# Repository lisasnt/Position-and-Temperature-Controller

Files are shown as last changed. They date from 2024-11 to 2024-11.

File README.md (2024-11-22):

# Position-and-Temperature-Controller

## About the project 
Nowadays, more and more biomedical applications require the implementation of embedded systems, to ensure performance and reliability while keeping costs down. Currently, at the laboratories of Pro-M Facility it's developed a calibration plant for a machine used in proton therapy. 

The goal of this application is to reduce the time taken for the calibration procedure of the machinery, making the process completely autonomous and without revision, thus reducing the duration of the operation from a couple of hours to a few tens of minutes.

The project consists in the development of the measurement and control part, in support of the innovative design proposed by the company, made using: an STM32H7 microcontroller, an absolute magnetic encoder and temperature sensors.

During the entire process a bottom-up approach was used, starting from the firmware and hardware development of the individual components, and then creating interconnections between them. 

The project has been successfully completed and, at the present time, is fully integrated within the macro project of Pro-M Facility.

## Components used

Main components used for the project:
- Nucleo STM32H723ZG
- Magnetic encoder WDGA 36A
- PTC thermistor
- NTC thermistor
- Custom PCB shield
- IHM03A1 step motor driver

# The main project

The entire system is called _Matrixx_ and consists of a mechanical structure needed to support the motor and a sensors control part (this one made by us). The Python GUI and the low level drivers to drive the motor are not shown in this repo because of a nondisclosure agreement with the company. 

[Matrixx project demo video](media/Embedded%20System%20Video%20-%20Proton.mp4)

## Custom PCB shield
This PCB allows the microcontroller to handle different voltages to supply all the internal and external components (involved voltages: 3.3, 5, 24 V)<br><br>
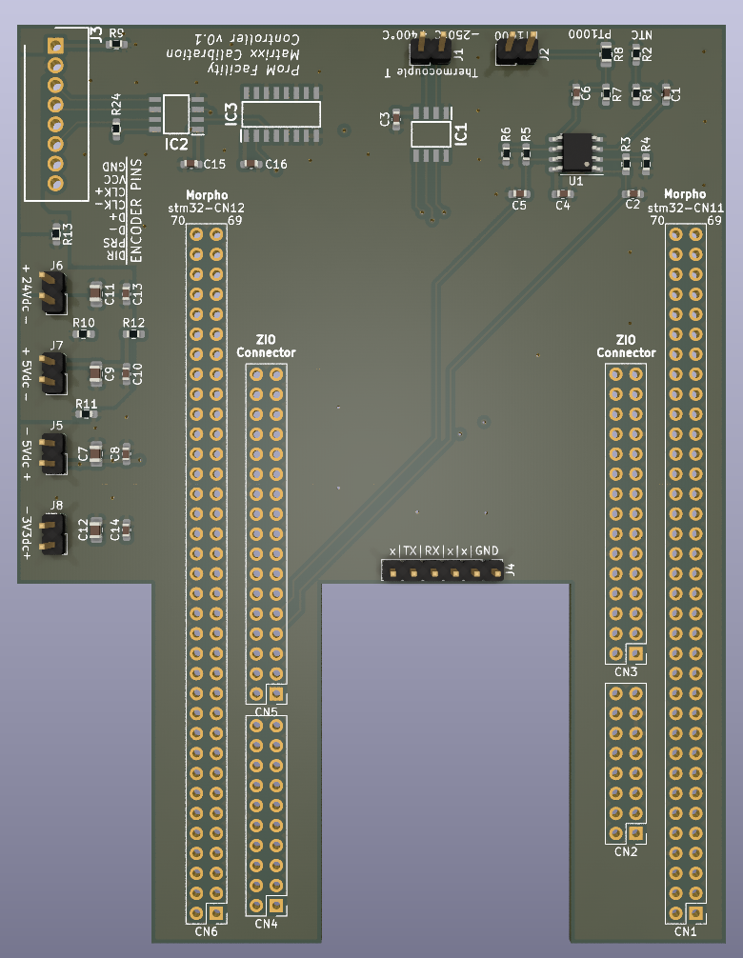
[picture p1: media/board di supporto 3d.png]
custom shield pcb

<br>_The custom PCB used as shield_<br><br>
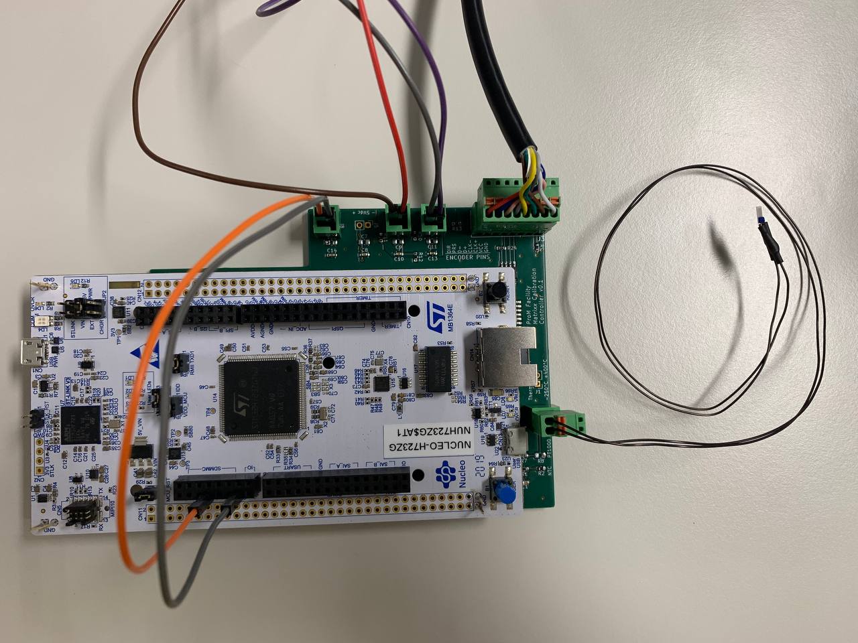
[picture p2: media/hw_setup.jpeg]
mounted board

<br>_The control subsystem made by us_

# Build and Run
## Repo structure
    📂 Firmware
    ┣ 📂 STM F4 <- it's not the version considered in the project
    ┣ 📂 STM H7 
    📂 Hardware
    ┣ 📂 HW_Encoder_Driver_Board <- just a prototype
    ┣ 📂 HW_Temperature_Sensors_Board <- Kicad project of the PCB shield

## Build the code and run
- Open STM32 Cube IDE
- `File` > `Import` > `Existing projects into Workspace`
- Select the root directory where the project is located
- Press `Finish`

Then you can build and run using the IDE

# Report
[Full report](/Academic_Project_Report.pdf)

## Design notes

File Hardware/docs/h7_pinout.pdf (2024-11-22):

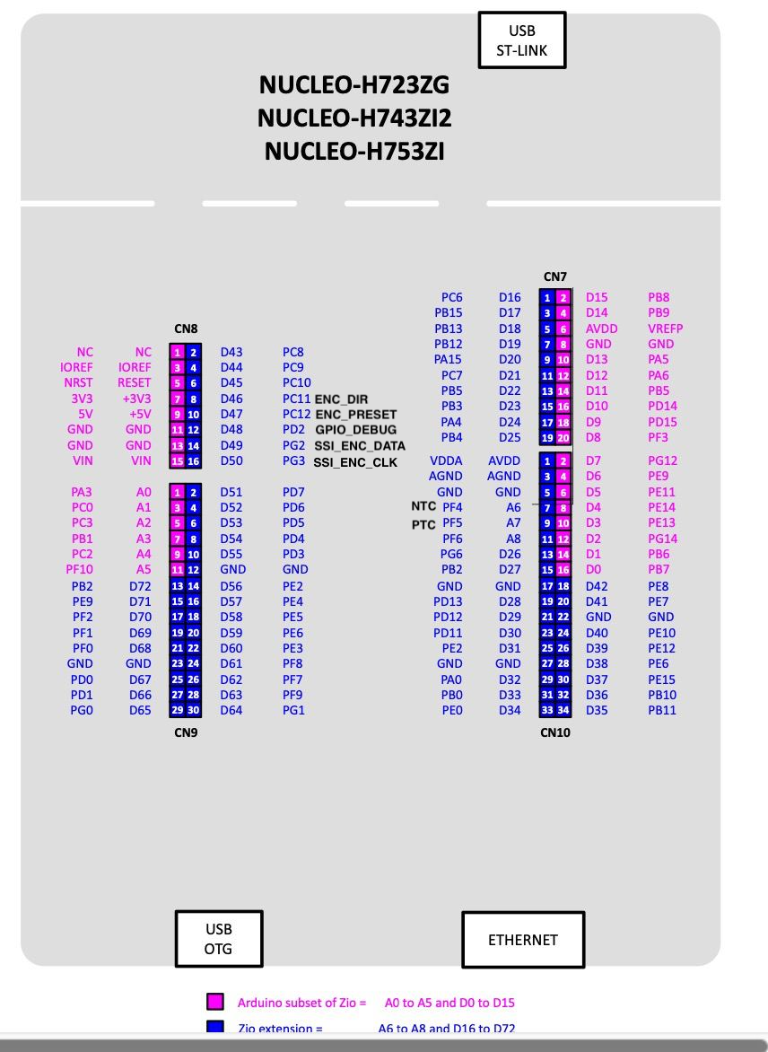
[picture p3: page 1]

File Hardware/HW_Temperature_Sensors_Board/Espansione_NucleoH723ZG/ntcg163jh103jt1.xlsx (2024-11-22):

P/N | NTCG163JH103JT1
R25 | 10 | kƒ¶ +/- | 5 | % |  |  |  |  |  |  |  |  |  | 2718334.pdf (farnell.com) (https://www.farnell.com/datasheets/2718334.pdf)
B25/85 | 3435 | K +/- | 3 | % |  |  | R kOhm | 10 |  |  | Ra | 10 |  | How to Use Temperature Protection Devices : Chip NTC Thermistors | Application Note | Tech Library | TDK Product Center (https://product.tdk.com/en/techlibrary/applicationnote/howto_chip-ntc-thermistor.html)
 |  |  |  |  |  |  | Vdd | 3.3 |  |  | Rb | 2.2
Temp | Min | Nom | Max | B25/T | -dT | dT
(degC) | (k ohm) | (k ohm) | (k ohm) | (K) | (degC) | (degC) | Vout-div (B) | Vout-div (T) | Ivdiv | V*I | Vout-ampli (T) |  | Vout-ampli (B)
-40 | 164 | 188.5 | 216.2 | 3140 | -2.4 | 2.4 | 3.133753149 | 0.1662468514 | 1.662468514e-05 | 2.76380156e-06 | 0.2028211587 |  | 3.823178841
-39 | 155.6 | 178.6 | 204.4 | 3144 | -2.4 | 2.4 | 3.125026511 | 0.1749734889 | 1.749734889e-05 | 3.061572181e-06 | 0.2134676564 |  | 3.812532344
-38 | 147.7 | 169.2 | 193.4 | 3148 | -2.4 | 2.4 | 3.115848214 | 0.1841517857 | 1.841517857e-05 | 3.391188018e-06 | 0.2246651786 |  | 3.801334821
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

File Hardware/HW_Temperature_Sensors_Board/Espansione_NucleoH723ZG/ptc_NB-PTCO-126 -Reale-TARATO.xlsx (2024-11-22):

P/N | NB-PTCO-126 |  | a | 0.0039083
TCR | 3850 | ppm/°C | b | -5.775e-07 |  |  |  |  |  |  |  | 2305684.pdf (farnell.com) (https://www.farnell.com/datasheets/2305684.pdf)
R 0°C | 1000 | ohm | c | -4.183e-12 | R kOhm | 6.8 |  |  | Ra | 2.28
 |  |  |  |  | Vdd | 3.3 |  |  | Rb | 10 |  | dr 0-100 | 0.7289419342 | Gain | 5.385964912
Temp |  | Nom
(degC) |  | (k ohm) |  |  | Vout-div (B) | Vout-div (T) | Ivdiv | V*I | Vout-ampli (T) |  | Vout-ampli (B)
-40 |  | 0.84 |  |  | 0.3638673695 | 2.936132631 | 0.0004317842104 | 0.001267775709 | 15.81390733 |  | 1.959776885
-39 |  | 0.85 |  |  | 0.3653867273 | 2.934613273 | 0.0004315607754 | 0.001266463979 | 15.80572412 |  | 1.967960093
-38 |  | 0.85 |  |  | 0.3669040039 | 2.933095996 | 0.0004313376465 | 0.001265154724 | 15.79755212 |  | 1.976132091
-37 |  | 0.85 |  |  | 0.3684192058 | 2.931580794 | 0.0004311148227 | 0.001263847934 | 15.7893913 |  | 1.984292915
-36 |  | 0.86 |  |  | 0.3699323393 | 2.930067661 | 0.000430892303 | 0.001262543602 | 15.78124161 |  | 1.992442599
-35 |  | 0.86 |  |  | 0.3714434107 | 2.928556589 | 0.0004306700867 | 0.00126124172 | 15.77310303 |  | 2.000581177
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

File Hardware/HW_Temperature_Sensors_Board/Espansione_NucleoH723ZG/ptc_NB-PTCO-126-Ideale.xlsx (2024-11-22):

P/N | NB-PTCO-126 |  | a | 0.0039083
TCR | 3850 | ppm/°C | b | -5.775e-07 |  |  |  |  |  |  |  | 2305684.pdf (farnell.com) (https://www.farnell.com/datasheets/2305684.pdf)
R 0°C | 1000 | ohm | c | -4.183e-12 | R kOhm | 6.8 |  |  | Ra | 2.4
 |  |  |  |  | Vdd | 3.3 |  |  | Rb | 10 |  | dr 0-100 | 0.699261888
Temp |  | Nom
(degC) |  | (k ohm) |  |  | Vout-div (B) | Vout-div (T) | Ivdiv | V*I | Vout-ampli (T) |  | Vout-ampli (B)
-40 |  | 0.84 |  |  | 0.3638673695 | 2.936132631 | 0.0004317842104 | 0.001267775709 | 15.17001859 |  | 1.879981409
-39 |  | 0.85 |  |  | 0.3653867273 | 2.934613273 | 0.0004315607754 | 0.001266463979 | 15.16216858 |  | 1.887831424
-38 |  | 0.85 |  |  | 0.3669040039 | 2.933095996 | 0.0004313376465 | 0.001265154724 | 15.15432931 |  | 1.895670687
-37 |  | 0.85 |  |  | 0.3684192058 | 2.931580794 | 0.0004311148227 | 0.001263847934 | 15.14650077 |  | 1.90349923
-36 |  | 0.86 |  |  | 0.3699323393 | 2.930067661 | 0.000430892303 | 0.001262543602 | 15.13868291 |  | 1.911317086
-35 |  | 0.86 |  |  | 0.3714434107 | 2.928556589 | 0.0004306700867 | 0.00126124172 | 15.13087571 |  | 1.919124289
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

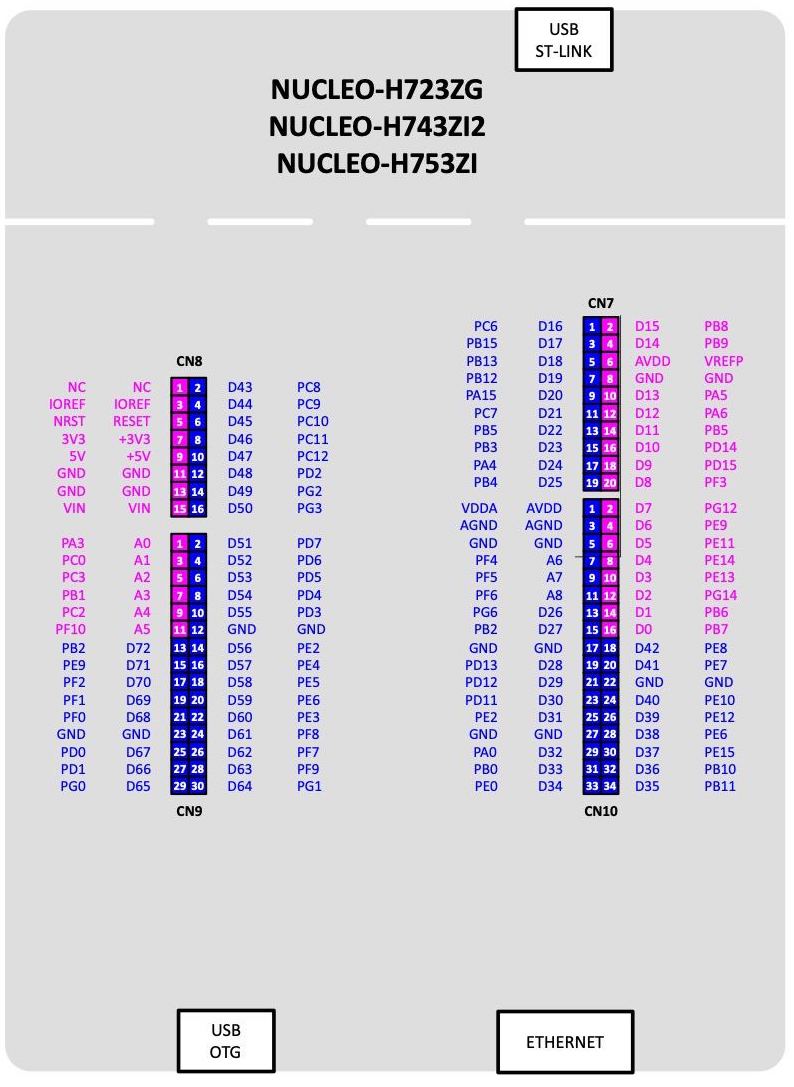
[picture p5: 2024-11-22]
media/pinout_stm.jpg

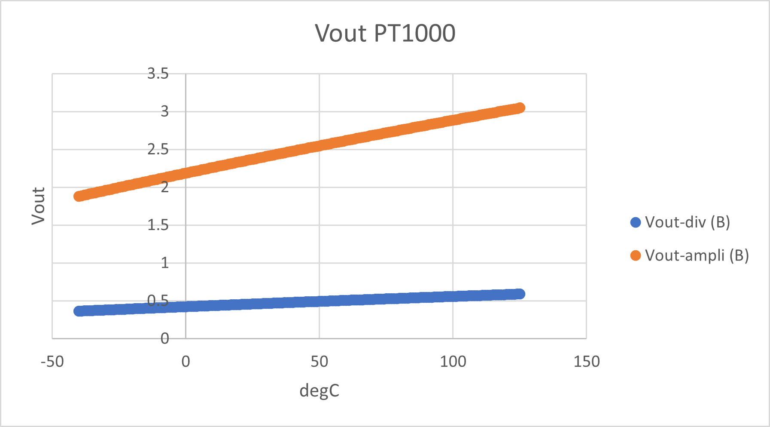
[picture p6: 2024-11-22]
Hardware/HW_Temperature_Sensors_Board/Espansione_NucleoH723ZG/Kicad_pj/pt1000_out.png

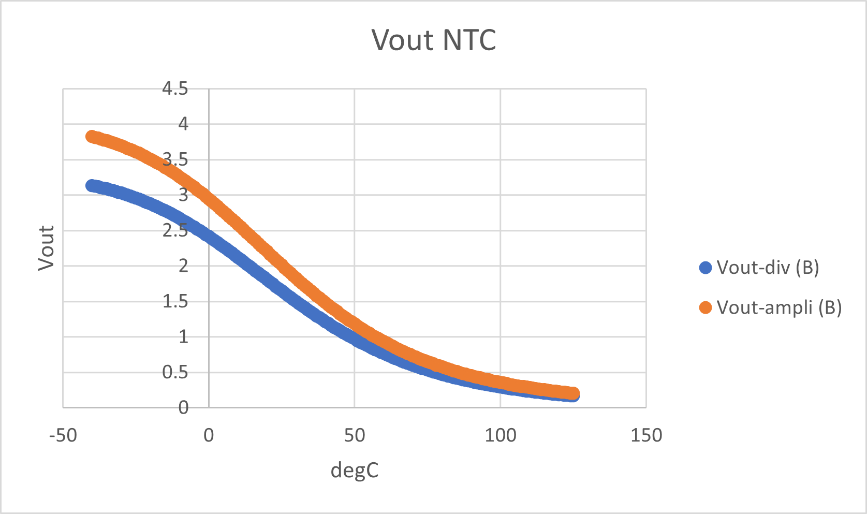
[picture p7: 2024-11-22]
Hardware/HW_Temperature_Sensors_Board/Espansione_NucleoH723ZG/Kicad_pj/ntc_out.png

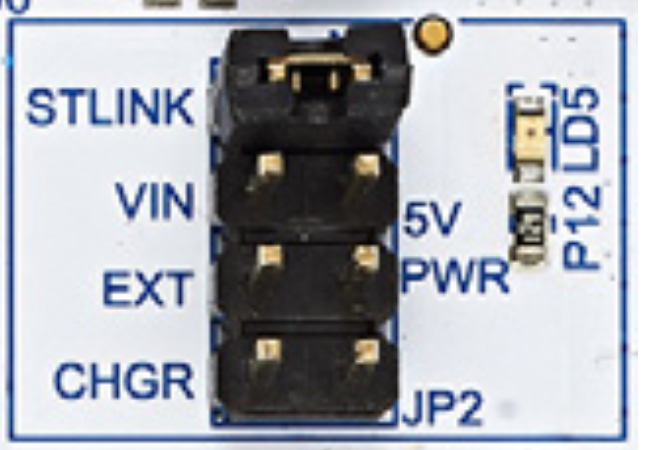
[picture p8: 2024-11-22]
media/jp2.png

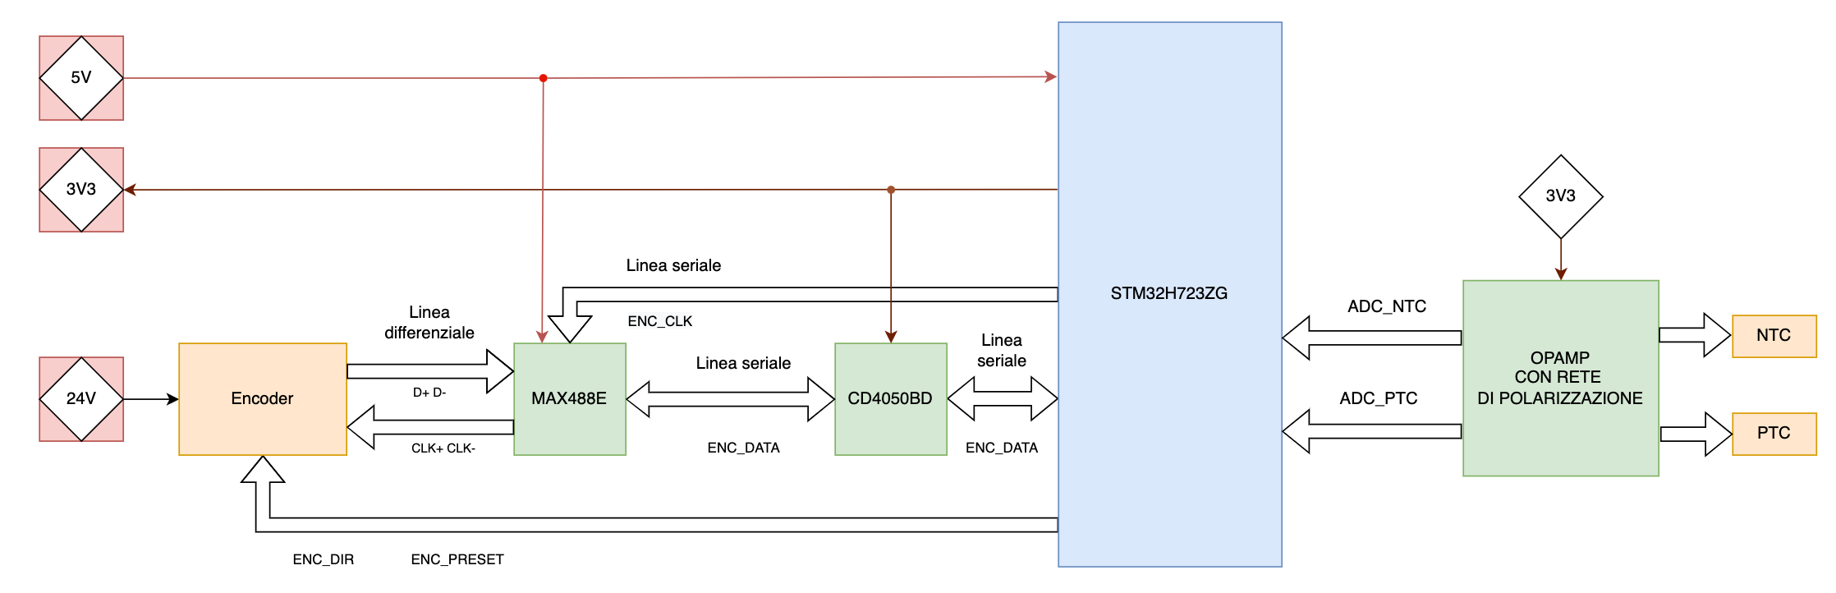
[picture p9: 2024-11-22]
media/Schema a blocchi board.png

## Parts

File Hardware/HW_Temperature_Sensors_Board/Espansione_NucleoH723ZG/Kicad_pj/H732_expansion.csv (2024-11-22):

Source: | C:\Users\maurizio.rossi\Documents\Projects\[2021][11] Proton Gantry\espansione\H732_expansion\H732_expansion.kicad_sch
Date: | 3/7/2022 11:16
Tool: | Eeschema (6.0.1)
Generator: | C:\Program Files\KiCad\bin\scripting\plugins/bom_csv_grouped_by_value_with_fp.py
Component Count: | 60
Ref | Qnty | Value | Cmp name | Footprint | Description | Vendor
C1, C2, C5, C6, | 4 | 10n | C_Small | Capacitor_SMD:C_0603_1608Metric_Pad1.08x0.95mm_HandSolder | Unpolarized capacitor, small symbol
C3, C4, C15, C16, | 4 | 100n | C_Small | Capacitor_SMD:C_0603_1608Metric_Pad1.08x0.95mm_HandSolder | Unpolarized capacitor, small symbol
C7, C9, C12, | 3 | 1u 10V | C_Small | Capacitor_SMD:C_0805_2012Metric_Pad1.18x1.45mm_HandSolder | Unpolarized capacitor, small symbol
C8, C10, C14, | 3 | 100n 10V | C_Small | Capacitor_SMD:C_0603_1608Metric_Pad1.08x0.95mm_HandSolder | Unpolarized capacitor, small symbol
C11, | 1 | 1u 50V | C_Small | Capacitor_SMD:C_0805_2012Metric_Pad1.18x1.45mm_HandSolder | Unpolarized capacitor, small symbol
C13, | 1 | 100n 50V | C_Small | Capacitor_SMD:C_0603_1608Metric_Pad1.08x0.95mm_HandSolder | Unpolarized capacitor, small symbol
CN1, | 1 | CN11 | Conn_02x35_Odd_Even | Connector_PinHeader_2.54mm:PinHeader_2x35_P2.54mm_Vertical | Generic connector, double row, 02x35, odd/even pin numbering scheme (row 1 odd numbers, row 2 even numbers), script generated (kicad-library-utils/schlib/autogen/connector/)
CN2, | 1 | CN8 | Conn_02x08_Odd_Even | Connector_PinHeader_2.54mm:PinHeader_2x08_P2.54mm_Vertical | Generic connector, double row, 02x08, odd/even pin numbering scheme (row 1 odd numbers, row 2 even numbers), script generated (kicad-library-utils/schlib/autogen/connector/)
CN3, | 1 | CN9 | Conn_02x15_Odd_Even | Connector_PinHeader_2.54mm:PinHeader_2x15_P2.54mm_Vertical | Generic connector, double row, 02x15, odd/even pin numbering scheme (row 1 odd numbers, row 2 even numbers), script generated (kicad-library-utils/schlib/autogen/connector/)
CN4, | 1 | CN7 | Conn_02x10_Odd_Even | Connector_PinHeader_2.54mm:PinHeader_2x10_P2.54mm_Vertical | Generic connector, double row, 02x10, odd/even pin numbering scheme (row 1 odd numbers, row 2 even numbers), script generated (kicad-library-utils/schlib/autogen/connector/)
CN5, | 1 | CN10 | Conn_02x17_Odd_Even | Connector_PinHeader_2.54mm:PinHeader_2x17_P2.54mm_Vertical | Generic connector, double row, 02x17, odd/even pin numbering scheme (row 1 odd numbers, row 2 even numbers), script generated (kicad-library-utils/schlib/autogen/connector/)
CN6, | 1 | C12 | Conn_02x35_Odd_Even | Connector_PinHeader_2.54mm:PinHeader_2x35_P2.54mm_Vertical | Generic connector, double row, 02x35, odd/even pin numbering scheme (row 1 odd numbers, row 2 even numbers), script generated (kicad-library-utils/schlib/autogen/connector/)
IC1, | 1 | MAX31855TASA+ | MAX31855TASA+ | SamacSys_Parts:SOIC127P600X175-8N | Sensor Interface Thermocouple To Digital Converter
IC2, | 1 | MAX490CSA+ | MAX490CSA+ | SamacSys_Parts:SOIC127P600X175-8N
IC3, | 1 | CD4050BD | CD4050BD | SamacSys_Parts:SOIC127P600X175-16N
J1, J6, J7, | 3 | Screw_Terminal_01x02 | Screw_Terminal_01x02 | Connector_PinHeader_2.54mm:PinHeader_1x02_P2.54mm_Vertical | Generic screw terminal, single row, 01x02, script generated (kicad-library-utils/schlib/autogen/connector/)
J2, | 1 | NB-PTCO-126 | Screw_Terminal_01x02 | Connector_PinHeader_2.54mm:PinHeader_1x02_P2.54mm_Vertical | Generic screw terminal, single row, 01x02, script generated (kicad-library-utils/schlib/autogen/connector/)
J3, | 1 | 691382000008 | 691382000008 | SamacSys_Parts:SHDR8W80P0X250_1X8_2200X810X1010P
J4, | 1 | Conn_01x06 | Conn_01x06 | Connector_PinHeader_2.54mm:PinHeader_1x06_P2.54mm_Vertical | Generic connector, single row, 01x06, script generated (kicad-library-utils/schlib/autogen/connector/)
J5, J8, | 2 | Conn_01x02 | Conn_01x02 | Connector_PinHeader_2.54mm:PinHeader_1x02_P2.54mm_Vertical | Generic connector, single row, 01x02, script generated (kicad-library-utils/schlib/autogen/connector/)
R1, | 1 | 10k | R_Small_US | Resistor_SMD:R_0603_1608Metric_Pad0.98x0.95mm_HandSolder | Resistor, small US symbol
R2, | 1 | NTCG163JH103JT1 | R_Small_US | Resistor_SMD:R_0603_1608Metric_Pad0.98x0.95mm_HandSolder | Resistor, small US symbol
R3, | 1 | 22k | R_Small_US | Resistor_SMD:R_0603_1608Metric_Pad0.98x0.95mm_HandSolder | Resistor, small US symbol
R4, | 1 | 100k | R_Small_US | Resistor_SMD:R_0603_1608Metric_Pad0.98x0.95mm_HandSolder | Resistor, small US symbol
R5, | 1 | 10K | R_Small_US | Resistor_SMD:R_0603_1608Metric_Pad0.98x0.95mm_HandSolder | Resistor, small US symbol
R6, | 1 | 2k4 | R_Small_US | Resistor_SMD:R_0603_1608Metric_Pad0.98x0.95mm_HandSolder | Resistor, small US symbol
R7, | 1 | 6k8 | R_Small_US | Resistor_SMD:R_0603_1608Metric_Pad0.98x0.95mm_HandSolder | Resistor, small US symbol
R8, | 1 | P1K0.0805.2P.B | R_Small_US | Resistor_SMD:R_0805_2012Metric_Pad1.20x1.40mm_HandSolder | Resistor, small US symbol
R9, R10, R11, R12, R13, R20, R21, R22, R23, | 9 | 0R | R_Small_US | Resistor_SMD:R_0603_1608Metric_Pad0.98x0.95mm_HandSolder | Resistor, small US symbol
R14, R15, R18, R19, | 4 | 47K | R_Small_US | Resistor_SMD:R_0603_1608Metric_Pad0.98x0.95mm_HandSolder | Resistor, small US symbol
R16, R17, | 2 | 2K2 | R_Small_US | Resistor_SMD:R_0603_1608Metric_Pad0.98x0.95mm_HandSolder | Resistor, small US symbol
R24, | 1 | 120R | R_Small_US | Resistor_SMD:R_0603_1608Metric_Pad0.98x0.95mm_HandSolder | Resistor, small US symbol
U1, | 1 | MCP6477 | MCP6477 | Package_SO:SOIC-8_3.9x4.9mm_P1.27mm
U2, U3, | 2 | SQ4532AEY-T1_GE3 | SQ4532AEY-T1_GE3 | footprints:SQ4532AEY-T1_GE3

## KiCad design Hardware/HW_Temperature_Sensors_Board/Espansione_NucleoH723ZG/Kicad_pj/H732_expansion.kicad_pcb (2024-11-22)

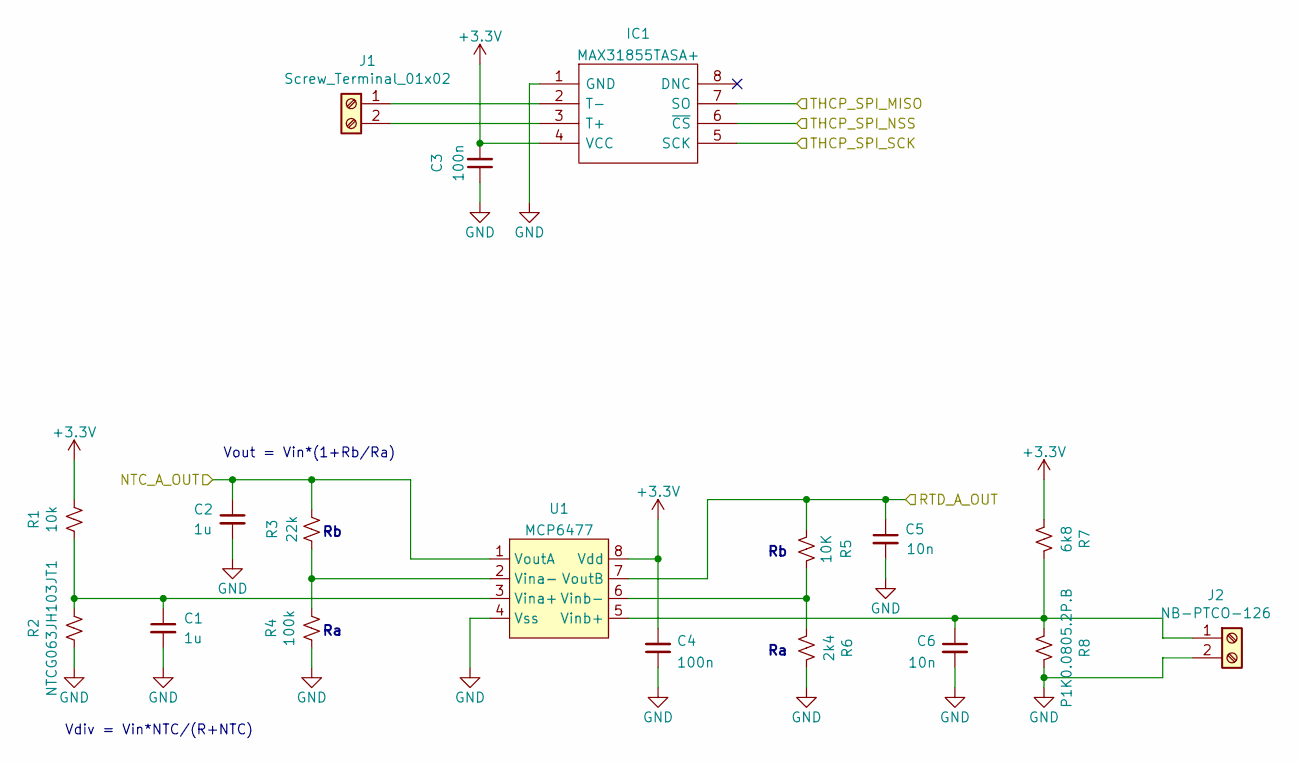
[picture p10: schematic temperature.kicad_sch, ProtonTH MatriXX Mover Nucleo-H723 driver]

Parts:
C1, C2: 1u; C_0603_1608Metric_Pad1.08x0.95mm_HandSolder
C3, C4: 100n; C_0603_1608Metric_Pad1.08x0.95mm_HandSolder
C5, C6: 10n; C_0603_1608Metric_Pad1.08x0.95mm_HandSolder
IC1: MAX31855TASA+; SOIC127P600X175-8N; Manufacturer_Part_Number MAX31855TASA+; Mouser Part Number 700-MAX31855TASA+
J1: Screw_Terminal_01x02; PinHeader_1x02_P2.54mm_Vertical
J2: NB-PTCO-126; PinHeader_1x02_P2.54mm_Vertical
R1: 10k; R_0603_1608Metric_Pad0.98x0.95mm_HandSolder
R2: NTCG063JH103JT1; R_0603_1608Metric_Pad0.98x0.95mm_HandSolder
R3: 22k; R_0603_1608Metric_Pad0.98x0.95mm_HandSolder
R4: 100k; R_0603_1608Metric_Pad0.98x0.95mm_HandSolder
R5: 10K; R_0603_1608Metric_Pad0.98x0.95mm_HandSolder
R6: 2k4; R_0603_1608Metric_Pad0.98x0.95mm_HandSolder
R7: 6k8; R_0603_1608Metric_Pad0.98x0.95mm_HandSolder
R8: P1K0.0805.2P.B; R_0805_2012Metric_Pad1.20x1.40mm_HandSolder
U1: MCP6477; SOIC-8_3.9x4.9mm_P1.27mm

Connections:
+3V3: C3.2, C4.2, IC1.4 (VCC), R1.2, R7.2, U1.8 (Vdd); also elsewhere on the board
/connectors/NTC_A_OUT: C2.1, R3.2, U1.1 (VoutA); also elsewhere on the board
/connectors/RTD_A_OUT: C5.1, R5.2, U1.7 (VoutB); also elsewhere on the board
/connectors/THCP_SPI_MISO: IC1.7 (SO); also elsewhere on the board
/connectors/THCP_SPI_NSS: IC1.6 (~CS); also elsewhere on the board
/connectors/THCP_SPI_SCK: IC1.5 (SCK); also elsewhere on the board
GND: C1.2, C2.2, C3.1, C4.1, C5.2, C6.2, IC1.1 (GND), J2.2, R2.1, R4.1, R6.1, R8.1, U1.4 (Vss); also elsewhere on the board
unnamed: C1.1, R1.1, R2.2, U1.3 (Vina+)
unnamed: C6.1, J2.1, R7.1, R8.2, U1.5 (Vinb+)
unnamed: IC1.2 (T-), J1.1
unnamed: IC1.3 (T+), J1.2
unnamed: R3.1, R4.2, U1.2 (Vina-)
unnamed: R5.1, R6.2, U1.6 (Vinb-)

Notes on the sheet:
Vdiv = Vin*NTC/(R+NTC)
Vout = Vin*(1+Rb/Ra)

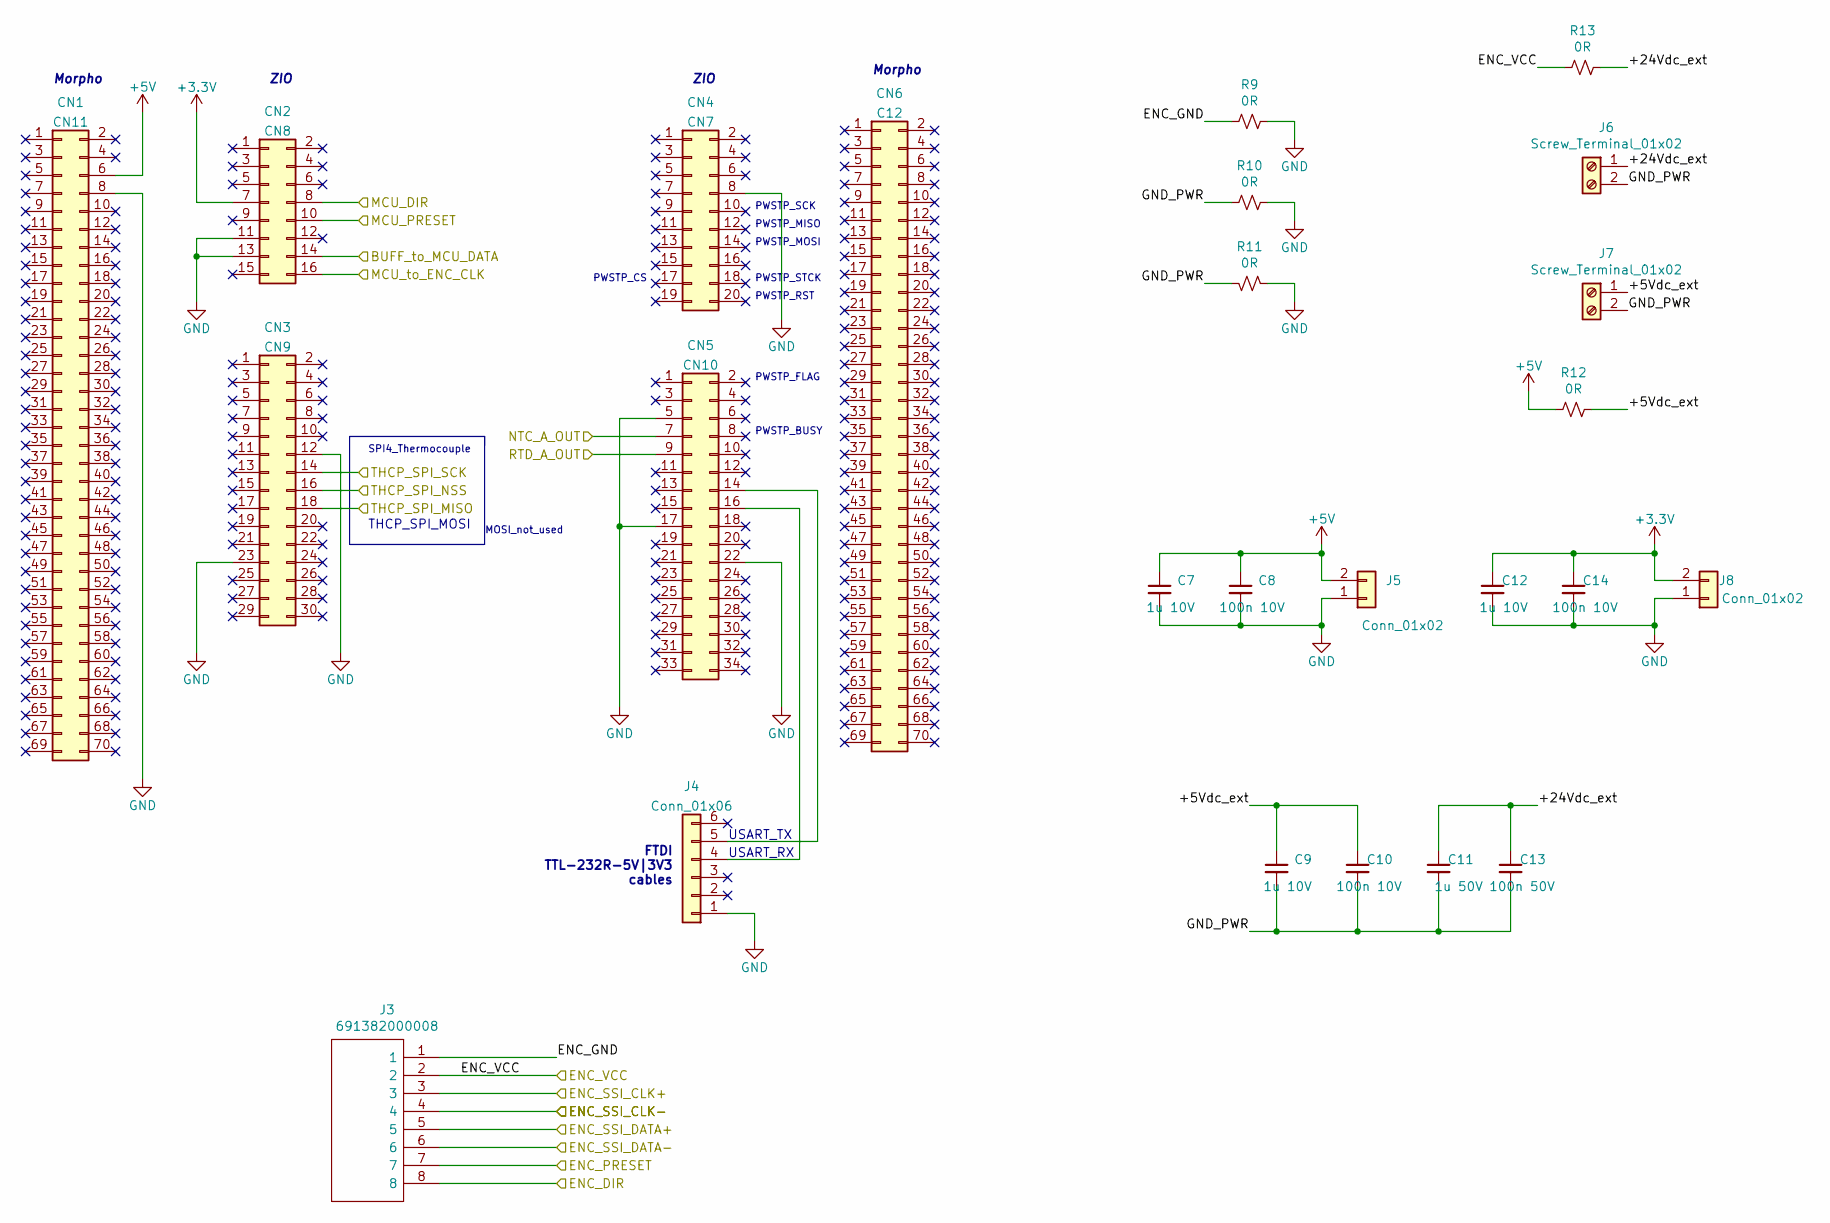
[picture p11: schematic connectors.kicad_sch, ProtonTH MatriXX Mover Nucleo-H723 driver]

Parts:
C7, C9, C12: 1u 10V; C_0805_2012Metric_Pad1.18x1.45mm_HandSolder
C8, C10, C14: 100n 10V; C_0603_1608Metric_Pad1.08x0.95mm_HandSolder
C11: 1u 50V; C_0805_2012Metric_Pad1.18x1.45mm_HandSolder
C13: 100n 50V; C_0603_1608Metric_Pad1.08x0.95mm_HandSolder
CN1: CN11; PinHeader_2x35_P2.54mm_Vertical
CN2: CN8; PinHeader_2x08_P2.54mm_Vertical
CN3: CN9; PinHeader_2x15_P2.54mm_Vertical
CN4: CN7; PinHeader_2x10_P2.54mm_Vertical
CN5: CN10; PinHeader_2x17_P2.54mm_Vertical
CN6: C12; PinHeader_2x35_P2.54mm_Vertical
J3: 691382000008; SHDR8W80P0X250_1X8_2200X810X1010P; Manufacturer_Part_Number 691382000008; Mouser Part Number 710-691382000008
J4: Conn_01x06; PinHeader_1x06_P2.54mm_Vertical
J5, J8: Conn_01x02; PinHeader_1x02_P2.54mm_Vertical
J6, J7: Screw_Terminal_01x02; PinHeader_1x02_P2.54mm_Vertical
R9, R10, R11, R12, R13: 0R; R_0603_1608Metric_Pad0.98x0.95mm_HandSolder

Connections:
+3V3: C12.1, C14.1, CN2.7, J8.2; also elsewhere on the board
+5V: C7.1, C8.1, CN1.6, J5.2, R12.1; also elsewhere on the board
/connectors/+5Vdc_ext: C9.1, C10.1, J7.1, R12.2
/connectors/+24Vdc_ext: C11.1, C13.1, J6.1, R13.2
/connectors/BUFF_to_MCU_DATA: CN2.14; also elsewhere on the board
/connectors/ENC_DIR: J3.8; also elsewhere on the board
/connectors/ENC_GND: J3.1, R9.1
/connectors/ENC_PRESET: J3.7; also elsewhere on the board
/connectors/ENC_SSI_CLK+: J3.3; also elsewhere on the board
/connectors/ENC_SSI_CLK-: J3.4; also elsewhere on the board
/connectors/ENC_SSI_DATA+: J3.5; also elsewhere on the board
/connectors/ENC_SSI_DATA-: J3.6; also elsewhere on the board
/connectors/ENC_VCC: J3.2, R13.1; also elsewhere on the board
/connectors/GND_PWR: C9.2, C10.2, C11.2, C13.2, J6.2, J7.2, R10.1, R11.2
/connectors/MCU_DIR: CN2.8; also elsewhere on the board
/connectors/MCU_PRESET: CN2.10; also elsewhere on the board
/connectors/MCU_to_ENC_CLK: CN2.16; also elsewhere on the board
/connectors/NTC_A_OUT: CN5.7; also elsewhere on the board
/connectors/RTD_A_OUT: CN5.9; also elsewhere on the board
/connectors/THCP_SPI_MISO: CN3.18; also elsewhere on the board
/connectors/THCP_SPI_NSS: CN3.16; also elsewhere on the board
/connectors/THCP_SPI_SCK: CN3.14; also elsewhere on the board
GND: C7.2, C8.2, C12.2, C14.2, CN1.8, CN2.11, CN2.13, CN3.12, CN3.23, CN4.8, CN5.5, CN5.17, CN5.22, J4.1, J5.1, J8.1, R9.2, R10.2, R11.1; also elsewhere on the board
unnamed: CN5.14, J4.5
unnamed: CN5.16, J4.4

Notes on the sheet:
PWSTP_BUSY
PWSTP_FLAG
Morpho
MOSI_not_used
FTDI TTL-232R-5V|3V3 cables
PWSTP_CS
PWSTP_MOSI
ZIO
PWSTP_MISO
USART_TX
THCP_SPI_MOSI
PWSTP_STCK
PWSTP_RST
PWSTP_SCK
USART_RX
SPI4_Thermocouple

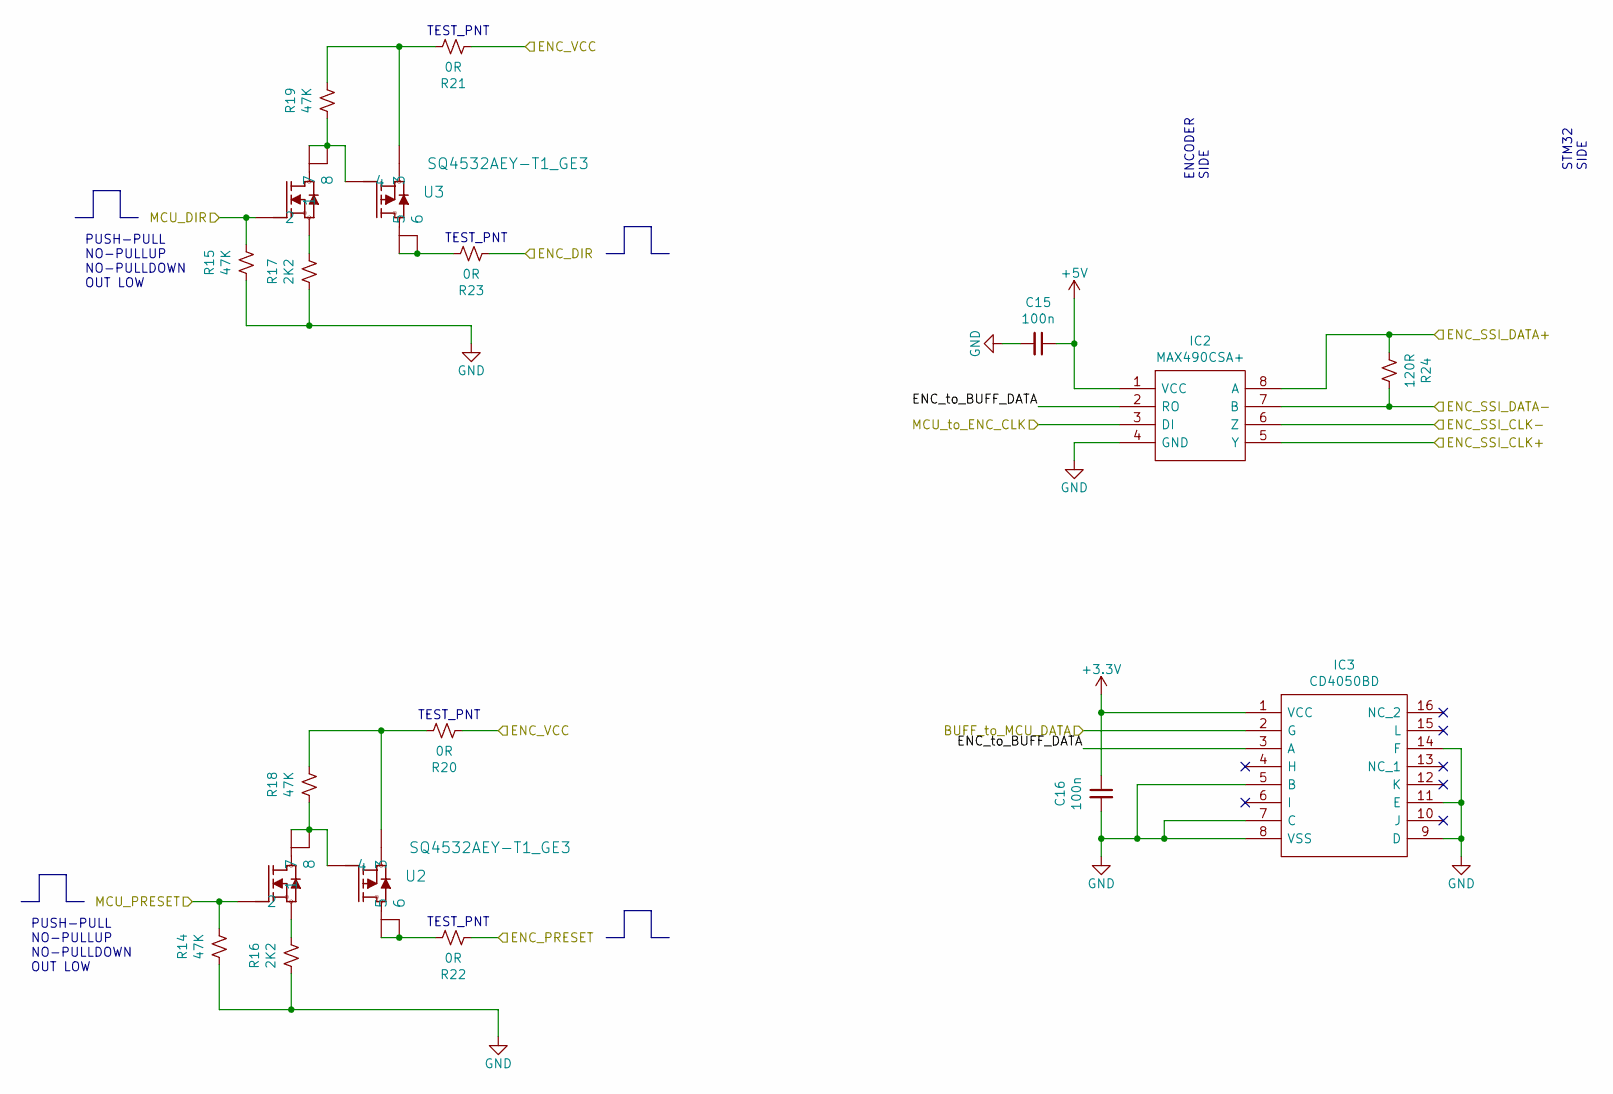
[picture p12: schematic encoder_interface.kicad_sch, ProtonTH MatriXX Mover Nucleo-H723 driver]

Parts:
C15, C16: 100n; C_0603_1608Metric_Pad1.08x0.95mm_HandSolder
IC2: MAX490CSA+; SOIC127P600X175-8N; Manufacturer_Part_Number MAX490CSA+; Mouser Part Number 700-MAX490CSA
IC3: CD4050BD; SOIC127P600X175-16N; Manufacturer_Part_Number CD4050BD; Mouser Part Number 595-CD4050BD
R14, R15, R18, R19: 47K; R_0603_1608Metric_Pad0.98x0.95mm_HandSolder
R16, R17: 2K2; R_0603_1608Metric_Pad0.98x0.95mm_HandSolder
R20, R21, R22, R23: 0R; R_0603_1608Metric_Pad0.98x0.95mm_HandSolder
R24: 120R; R_0603_1608Metric_Pad0.98x0.95mm_HandSolder
U2, U3: SQ4532AEY-T1_GE3

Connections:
+3V3: C16.1, IC3.1 (VCC); also elsewhere on the board
+5V: C15.1, IC2.1 (VCC); also elsewhere on the board
/connectors/BUFF_to_MCU_DATA: IC3.2 (G); also elsewhere on the board
/connectors/ENC_DIR: R23.1; also elsewhere on the board
/connectors/ENC_PRESET: R22.1; also elsewhere on the board
/connectors/ENC_SSI_CLK+: IC2.5 (Y); also elsewhere on the board
/connectors/ENC_SSI_CLK-: IC2.6 (Z); also elsewhere on the board
/connectors/ENC_SSI_DATA+: IC2.8 (A), R24.1; also elsewhere on the board
/connectors/ENC_SSI_DATA-: IC2.7 (B), R24.2; also elsewhere on the board
/connectors/ENC_VCC: R20.1, R21.1; also elsewhere on the board
/connectors/MCU_DIR: R15.2, U3.2; also elsewhere on the board
/connectors/MCU_PRESET: R14.2, U2.2; also elsewhere on the board
/connectors/MCU_to_ENC_CLK: IC2.3 (DI); also elsewhere on the board
/encoder_interface/ENC_to_BUFF_DATA: IC2.2 (RO), IC3.3 (A)
GND: C15.2, C16.2, IC2.4 (GND), IC3.5 (B), IC3.7 (C), IC3.8 (VSS), IC3.9 (D), IC3.11 (E), IC3.14 (F), R14.1, R15.1, R16.1, R17.1; also elsewhere on the board
unnamed: R16.2, U2.1
unnamed: R17.2, U3.1
unnamed: R18.1, U2.4, U2.7, U2.8
unnamed: R18.2, R20.2, U2.3
unnamed: R19.1, U3.4, U3.7, U3.8
unnamed: R19.2, R21.2, U3.3
unnamed: R22.2, U2.5, U2.6
unnamed: R23.2, U3.5, U3.6

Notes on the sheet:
TEST_PNT
STM32 SIDE
PUSH-PULL NO-PULLUP NO-PULLDOWN OUT LOW
ENCODER SIDE

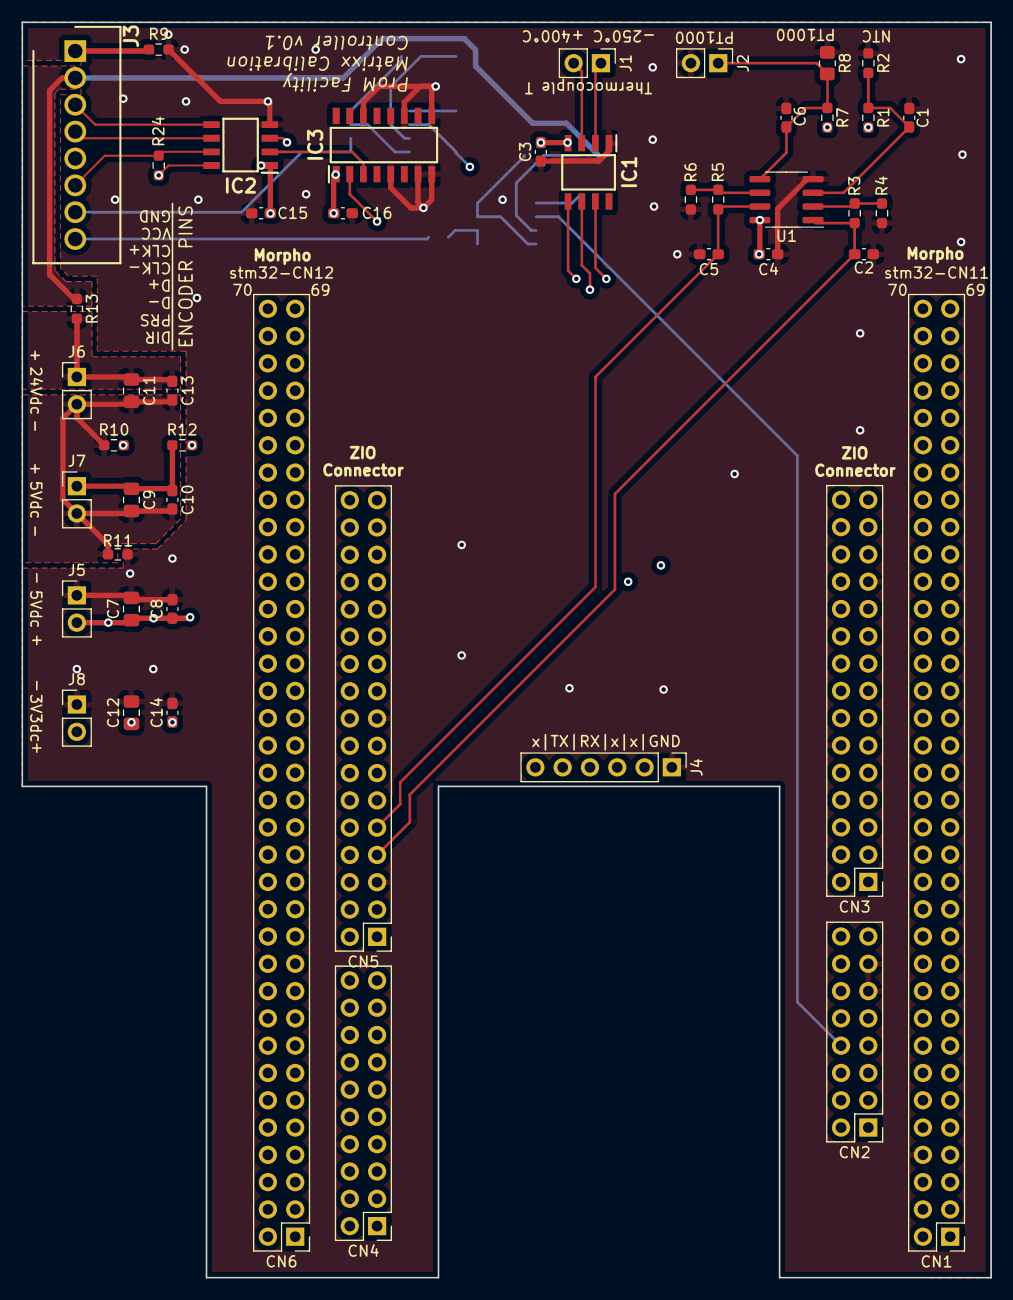
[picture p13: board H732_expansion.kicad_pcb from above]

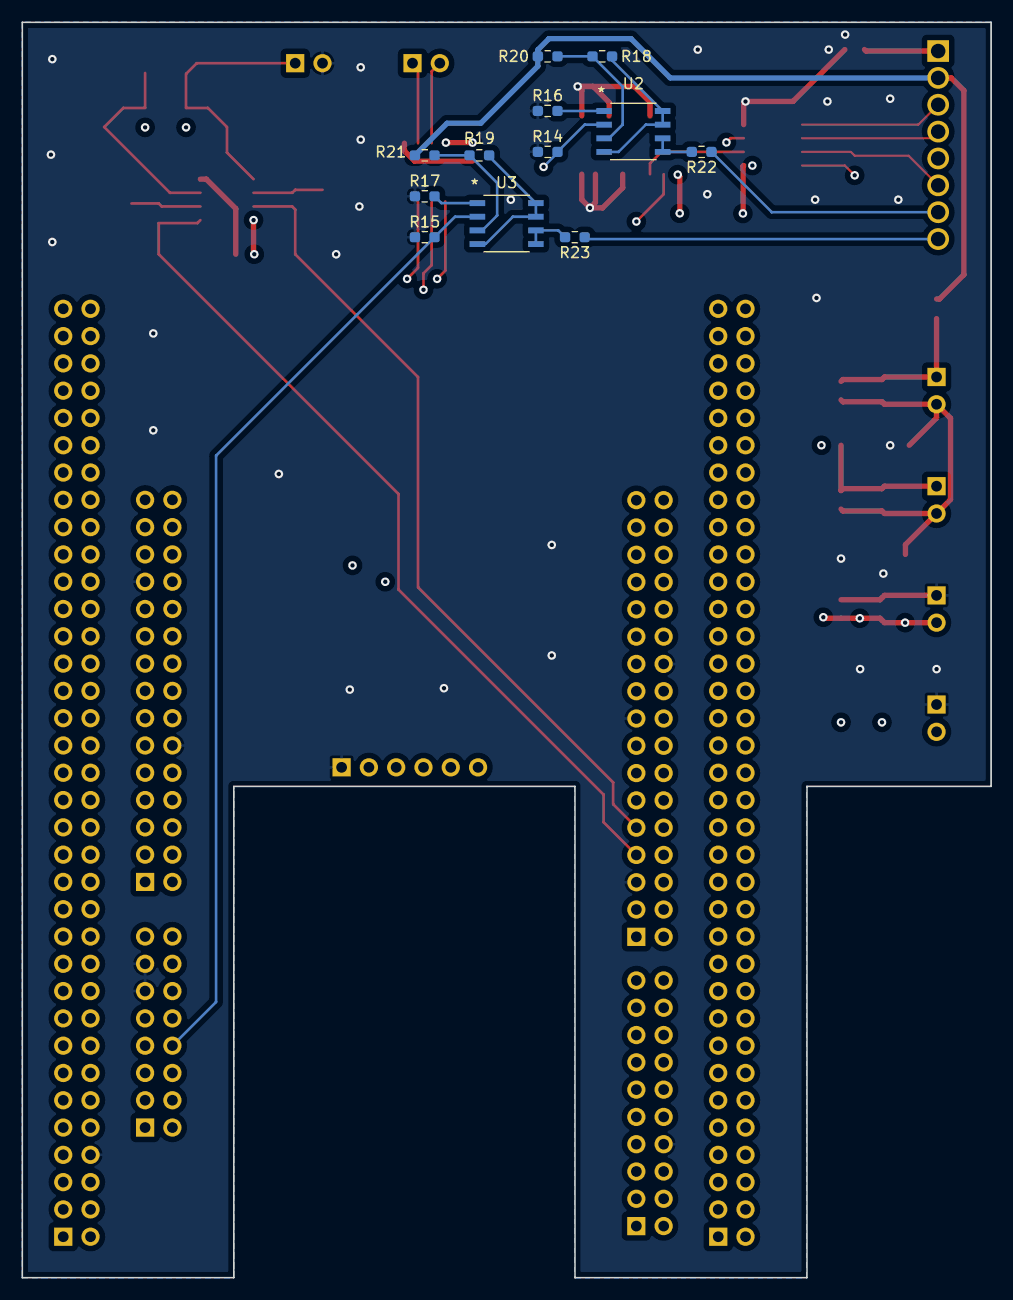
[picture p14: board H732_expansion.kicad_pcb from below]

Board: 4 copper layers, 90.2 x 116.8 mm, 60 parts (12 on the bottom side), 40 nets.

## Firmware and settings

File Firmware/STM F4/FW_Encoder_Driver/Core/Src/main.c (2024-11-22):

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
/* Includes ------------------------------------------------------------------*/
#include "main.h"
#include "adc.h"
#include "tim.h"
#include "usart.h"
#include "gpio.h"

/* USER CODE BEGIN Includes */
#include <stdio.h>
#include <string.h>
#include "ntc.h"
#include "ptc.h"
/* USER CODE END Includes */

/* USER CODE BEGIN PD */
//#define WORK
#define TRUE   1
#define FALSE   0
#define ENC_BITs   27  // 13 multiturn, 12 angle, 2 stop-bits
#define AVG_MEAS    3
#define ENC_BUFF_SIZE   80

/* USER CODE END PD */


/* USER CODE BEGIN PV */
uint32_t enc_clk_count = 0;
uint32_t enc_bits[AVG_MEAS];
uint8_t ping = TRUE;
uint8_t sampl_cycles = 3;
uint8_t i = 0;
uint32_t angle[AVG_MEAS];
uint16_t turn[AVG_MEAS];
uint8_t tx_buff[ENC_BUFF_SIZE];
uint8_t tx_ENC_BUFF_SIZE;
/* USER CODE END PV */

void SystemClock_Config(void);
/* USER CODE BEGIN PFP */
//void setInitialClockState( GPIO_PinState PinState);
//void runClock();
//void readEncoderBit(GPIO_TypeDef*, uint16_t);
//void println(UART_HandleTypeDef *, char[]);
//void nop(uint16_t);
void getTemperature();
/* USER CODE END PFP */

/* USER CODE BEGIN 0 */
typedef struct{
	uint64_t totalBits;
	uint64_t STbits;
	uint64_t MTbits;
} encoderStruct;

encoderStruct encoder;
/* USER CODE END 0 */

/**
  * @brief  The application entry point.
  * @retval int
  */
int main(void)
{
  /* MCU Configuration--------------------------------------------------------*/

  /* Reset of all peripherals, Initializes the Flash interface and the Systick. */
  HAL_Init();

  /* Configure the system clock */
  SystemClock_Config();

  /* Initialize all configured peripherals */
  MX_GPIO_Init();
  MX_USART2_UART_Init();
  MX_TIM11_Init();
  MX_ADC1_Init();
  /* USER CODE BEGIN 2 */
	//setInitialClockState(GPIO_PIN_SET);

	//println(&huart2, "HELLO! \r\n");
	//println(&huart2, "------------------------------");


	memset(tx_buff, (uint8_t)0x0, sizeof(uint8_t)*ENC_BUFF_SIZE);
	memset(enc_bits,(uint8_t)0x0, sizeof(uint32_t)*AVG_MEAS);
	tx_ENC_BUFF_SIZE = (uint8_t) sprintf((char *) tx_buff, "Hello\n\r");
	HAL_UART_Transmit(&huart2, (uint8_t*)tx_buff, tx_ENC_BUFF_SIZE, 500);

	// Set initial encoder position to 0
	HAL_GPIO_WritePin(ENC_PRESET_GPIO_Port, ENC_PRESET_Pin, GPIO_PIN_SET);
	HAL_Delay(2500);
	HAL_GPIO_WritePin(ENC_PRESET_GPIO_Port, ENC_PRESET_Pin, GPIO_PIN_RESET);
	HAL_Delay(500);

  /* USER CODE END 2 */

  /* Infinite loop */
  /* USER CODE BEGIN WHILE */
	while (1)
	{

//		getTemperature();
//		HAL_Delay(500);

    /* USER CODE END WHILE */

    /* USER CODE BEGIN 3 */
		memset(enc_bits,(uint8_t)0x0, sizeof(uint32_t)*AVG_MEAS);

		    for (i = 0; i < AVG_MEAS; i++)
		    {
		      ping = TRUE;
		      enc_clk_count = 0;
		      HAL_TIM_Base_Start_IT(&htim11);



		      while (enc_clk_count < (ENC_BITs * 4) ) // Every data bit it's 4 timer interrupts (encoder_clk_count)
		      {
		        while (ping){}

		        if ((enc_clk_count % 4) == 0)
		        {
		          HAL_GPIO_TogglePin(GPIO_DEBUG_GPIO_Port, GPIO_DEBUG_Pin);
		          enc_bits[i] <<= 1;
		          enc_bits[i] |= ( ((uint32_t) HAL_GPIO_ReadPin(SSI_ENC_DATA_GPIO_Port, SSI_ENC_DATA_Pin)) & 0x00000001);
		          HAL_GPIO_TogglePin(GPIO_DEBUG_GPIO_Port, GPIO_DEBUG_Pin);
		        }
		        else if ((enc_clk_count % 2) == 0)
		        {
		        	int x = 0;
		        }
		        else
		        {
		          HAL_GPIO_TogglePin(SSI_ENC_CLK_GPIO_Port, SSI_ENC_CLK_Pin);
		        }
		        ping = TRUE;
		      }

		      HAL_GPIO_WritePin(SSI_ENC_CLK_GPIO_Port, SSI_ENC_CLK_Pin, GPIO_PIN_SET);
		      HAL_TIM_Base_Stop_IT(&htim11);
		      HAL_Delay(5);
		    }

		    for (i = 0; i < AVG_MEAS; i++)
		    {
		      enc_bits[i] >>= 2;
		      //13 bits angle
		      angle[i] = (int32_t) ((enc_bits[i] & 0x00001FFF) * 44); // 360 / 2^13 * 1000 = 44 [mDeg]
		      //12 bits multi-turn
		      turn[i]  = (int16_t)((enc_bits[i] & 0x01FFE000) >> 13);
		    }
		    tx_ENC_BUFF_SIZE = (uint8_t) sprintf((char *) tx_buff, "RES:\n\r%lu|%lu|%lu mDeg\n\r%u|%u|%u turns\n\r",
		                          angle[0], angle[1], angle[2], turn[0], turn[1], turn[2]);
		    HAL_UART_Transmit(&huart2, (uint8_t*)tx_buff, tx_ENC_BUFF_SIZE, 1000);
		    HAL_Delay(500);

	}
  /* USER CODE END 3 */
}

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
/* USER CODE BEGIN 4 */
void HAL_TIM_PeriodElapsedCallback(TIM_HandleTypeDef *htim)
{
	if(htim->Instance == TIM11)
	{
		enc_clk_count++;
		ping = FALSE;
	}
}


#ifdef WORK
void setInitialClockState( GPIO_PinState PinState){
	if(PinState==GPIO_PIN_RESET || PinState==GPIO_PIN_SET){
		HAL_GPIO_WritePin(SSI_CLK_GPIO_Port,  SSI_CLK_Pin, PinState);
	}else{
		printf("error");
	}
}

void runClock(){
	// Inizio trasmissione
	encoder.totalBits = 0U;
	for(int i=0; i<N_BIT; i++) {
		HAL_GPIO_WritePin(SSI_CLK_GPIO_Port, SSI_CLK_Pin, GPIO_PIN_RESET);
		nop(4);
		HAL_GPIO_WritePin(SSI_CLK_GPIO_Port, SSI_CLK_Pin, GPIO_PIN_SET);
		nop(6);
		HAL_GPIO_WritePin(DEBUG_LINE_GPIO_Port, DEBUG_LINE_Pin, GPIO_PIN_SET);
		readEncoderBit(DATA_IN_GPIO_Port, DATA_IN_Pin);
		HAL_GPIO_WritePin(DEBUG_LINE_GPIO_Port, DEBUG_LINE_Pin, GPIO_PIN_RESET);
		nop(2);
		//HAL_GPIO_WritePin(SSI_CLK_GPIO_Port, SSI_CLK_Pin, GPIO_PIN_RESET);
		//nop(1);
	}
	HAL_GPIO_WritePin(SSI_CLK_GPIO_Port, SSI_CLK_Pin, GPIO_PIN_SET);
	//encoder.STbits = (encoder.totalBits & 0x1FFF000) >> 12; //primi 13 bit di maschera Single turn
	//encoder.MTbits = (encoder.totalBits & 0xFFF); //12 bit di maschera Multi turn
	//printf(".");
	//println(&huart2, stbit);
}

void readEncoderBit(GPIO_TypeDef* GPIOx, uint16_t GPIO_Pin){
	encoder.totalBits <<= 1;
	if(HAL_GPIO_ReadPin(GPIOx, GPIO_Pin) == GPIO_PIN_SET){
		encoder.totalBits |= 1;
	}
}
void println(UART_HandleTypeDef *huart, char out[]){
	HAL_UART_Transmit(huart, (uint8_t *) out, strlen(out), 10);
	char newline[2] = "\r\n";
	HAL_UART_Transmit(huart, (uint8_t *) newline, 2, 10);
}

void nop(uint16_t N){
	for(int i=0; i<N; i++){
		__asm("nop"); //1/84Mhz=1.25x10e-8s
	}
}

void getSample(){

}
#endif

void getTemperature(){
	double ptc_volt = get_ptc_volt(&hadc1, 200);
	get_ptc_temp_zone(ptc_volt);
	HAL_Delay(1000);

	double ntc_volt = get_ntc_volt(&hadc1, 200);
	get_ntc_temp_zone(ntc_volt);
	HAL_Delay(1000);
	// println(&huart2, "------------------------------");
}
/* USER CODE END 4 */
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


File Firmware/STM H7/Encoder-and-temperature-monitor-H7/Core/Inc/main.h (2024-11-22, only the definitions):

#define B1_Pin GPIO_PIN_13
#define B1_GPIO_Port GPIOC
#define NTC_Pin GPIO_PIN_4
#define NTC_GPIO_Port GPIOF
#define PTC_Pin GPIO_PIN_5
#define PTC_GPIO_Port GPIOF
#define MCO_Pin GPIO_PIN_0
#define MCO_GPIO_Port GPIOH
#define RMII_MDC_Pin GPIO_PIN_1
#define RMII_MDC_GPIO_Port GPIOC
#define RMII_REF_CLK_Pin GPIO_PIN_1
#define RMII_REF_CLK_GPIO_Port GPIOA
#define RMII_MDIO_Pin GPIO_PIN_2
#define RMII_MDIO_GPIO_Port GPIOA
#define RMII_CRS_DV_Pin GPIO_PIN_7
#define RMII_CRS_DV_GPIO_Port GPIOA
#define RMII_RXD0_Pin GPIO_PIN_4
#define RMII_RXD0_GPIO_Port GPIOC
#define RMII_RXD1_Pin GPIO_PIN_5
#define RMII_RXD1_GPIO_Port GPIOC
#define LED_GREEN_Pin GPIO_PIN_0
#define LED_GREEN_GPIO_Port GPIOB
#define TEST_OUT_Pin GPIO_PIN_0
#define TEST_OUT_GPIO_Port GPIOG
#define RMII_TXD1_Pin GPIO_PIN_13
#define RMII_TXD1_GPIO_Port GPIOB
#define LED_RED_Pin GPIO_PIN_14
#define LED_RED_GPIO_Port GPIOB
#define STLK_VCP_RX_Pin GPIO_PIN_8
#define STLK_VCP_RX_GPIO_Port GPIOD
#define STLK_VCP_TX_Pin GPIO_PIN_9
#define STLK_VCP_TX_GPIO_Port GPIOD
#define USB_FS_PWR_EN_Pin GPIO_PIN_10
#define USB_FS_PWR_EN_GPIO_Port GPIOD
#define SSI_ENC_DATA_Pin GPIO_PIN_2
#define SSI_ENC_DATA_GPIO_Port GPIOG
#define SSI_ENC_CLK_Pin GPIO_PIN_3
#define SSI_ENC_CLK_GPIO_Port GPIOG
#define USB_FS_OVCR_Pin GPIO_PIN_7
#define USB_FS_OVCR_GPIO_Port GPIOG
#define USB_FS_VBUS_Pin GPIO_PIN_9
#define USB_FS_VBUS_GPIO_Port GPIOA
#define USB_FS_ID_Pin GPIO_PIN_10
#define USB_FS_ID_GPIO_Port GPIOA
#define USB_FS_DM_Pin GPIO_PIN_11
#define USB_FS_DM_GPIO_Port GPIOA
#define USB_FS_DP_Pin GPIO_PIN_12
#define USB_FS_DP_GPIO_Port GPIOA
#define SWDIO_Pin GPIO_PIN_13
#define SWDIO_GPIO_Port GPIOA
#define SWCLK_Pin GPIO_PIN_14
#define SWCLK_GPIO_Port GPIOA
#define ENC_DIR_Pin GPIO_PIN_11
#define ENC_DIR_GPIO_Port GPIOC
#define ENC_PRESET_Pin GPIO_PIN_12
#define ENC_PRESET_GPIO_Port GPIOC
#define GPIO_DEBUG_Pin GPIO_PIN_2
#define GPIO_DEBUG_GPIO_Port GPIOD
#define RMII_TX_EN_Pin GPIO_PIN_11
#define RMII_TX_EN_GPIO_Port GPIOG
#define RMII_TXD0_Pin GPIO_PIN_13
#define RMII_TXD0_GPIO_Port GPIOG
#define SWO_Pin GPIO_PIN_3
#define SWO_GPIO_Port GPIOB
#define LED_YELLOW_Pin GPIO_PIN_1
#define LED_YELLOW_GPIO_Port GPIOE

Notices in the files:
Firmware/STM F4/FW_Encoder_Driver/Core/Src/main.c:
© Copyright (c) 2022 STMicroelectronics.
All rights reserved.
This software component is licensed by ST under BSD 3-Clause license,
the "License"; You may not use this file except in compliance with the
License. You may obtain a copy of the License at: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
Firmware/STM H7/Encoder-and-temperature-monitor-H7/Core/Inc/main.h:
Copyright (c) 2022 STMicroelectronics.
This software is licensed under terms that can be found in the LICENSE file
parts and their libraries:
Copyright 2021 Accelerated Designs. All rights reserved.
